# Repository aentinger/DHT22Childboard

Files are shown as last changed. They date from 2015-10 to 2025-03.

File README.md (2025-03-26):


💾 DHT22 Childboard
====================



# 📸 Image

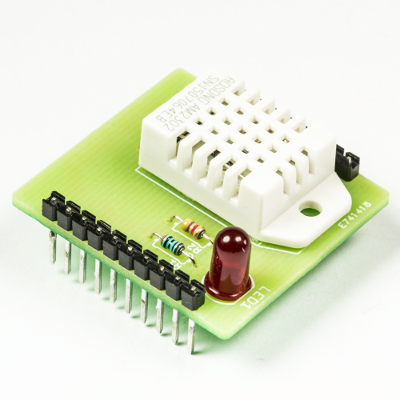
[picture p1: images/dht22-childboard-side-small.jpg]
LXRobotics P6_4 DHT22 Childboard


# 📂 Description

The LXRobotics DHT22 Humidity/Temperature Sensor Childboard is based on the known DHT22 sensor and allows the measurement of temperature and of the air humidity. For a quick and easy start, an open source Arduino library with sample programs is available.

**Features**

* Measurement of Temperature and Air Humidity
* Red Status-LED controlled by user
* Can be used with the Radioshield the Childboard Adaptershield
* Arduino Library with example programs is available on GitHub

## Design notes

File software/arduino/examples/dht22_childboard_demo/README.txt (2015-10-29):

DHT22 Arduino Library for example file dht22_childboard_demo.ino : https://github.com/markruys/arduino-DHT

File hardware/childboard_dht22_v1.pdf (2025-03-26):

Menge | Schaltplan | Bezeichnung | Farnell Bestell Nummer | Preis (1 Stück) | Gesamtpreis | Wird bestückt | Footprint | Säckchen | ESD
1 | LED1 | LED Rot, 5 mm, Uf=1.9V, If=10 mA | 1660489 | € 0,35 | € 0,35 | | | S1
1 | R1 | Widerstand, 300 R, 0.25 W | 2329916 | € 0,03 | € 0,03
1 | R2 | Widerstand, 4k7, 1/8 W | 1700245 | € 0,01 | € 0,01
1 | IC1 | DHT22 | - | € | 5,00 | € | 5,00 | Hinweis: Via Alibaba beziehen
2 | J1 | RF Childboard Connector | 1022261 | € | 0,36 | € | 0,72
| | | | Summe | | € | 6,11

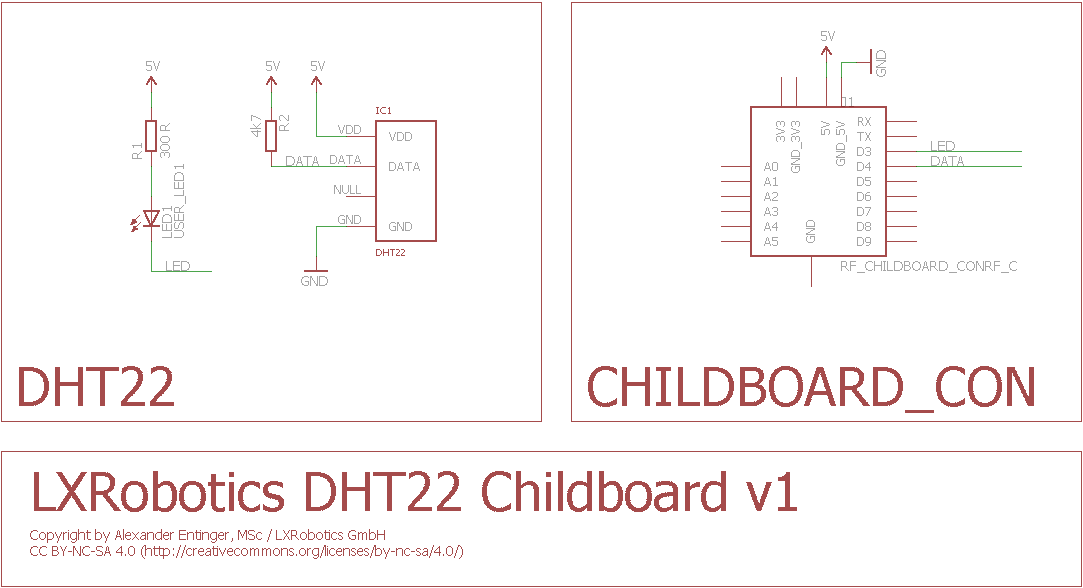
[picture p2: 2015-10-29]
hardware/lxr_childboard_dht22_v1.png

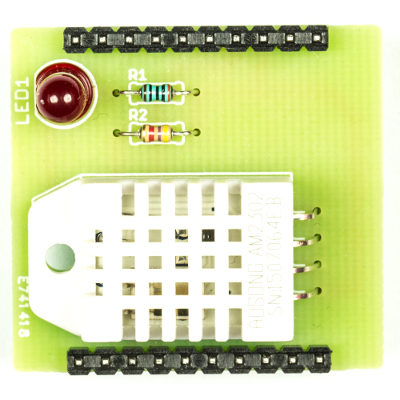
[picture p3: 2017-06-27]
images/dht22-childboard-top-small.jpg

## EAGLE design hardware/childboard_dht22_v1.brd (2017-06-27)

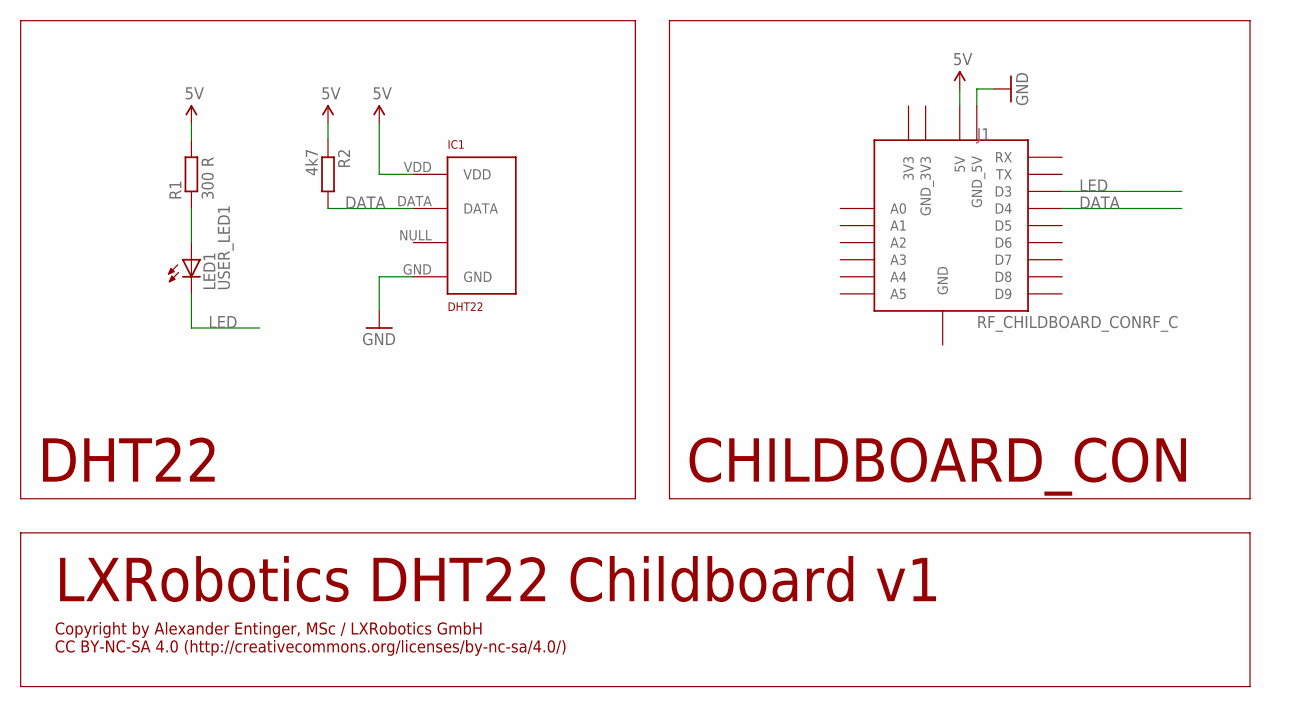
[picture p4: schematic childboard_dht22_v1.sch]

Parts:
IC1: DHT22; RHT03_DHT-22/RA
J1: RF_CHILDBOARD_CONRF_C; RF_CHILDBOARD_CON
LED1: USER_LED1; LED5MM
R1: 300 R; 0204/7
R2: 4k7; 0204/7

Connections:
5V: IC1.VDD, J1.5V, R1.2, R2.1
DATA: IC1.DATA, J1.D4, R2.2
GND: IC1.GND, J1.GND_5V
LED: J1.D3, LED1.K (C)
unnamed: LED1.A, R1.1

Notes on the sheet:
DHT22
CHILDBOARD_CON
LXRobotics DHT22 Childboard v1
Copyright by Alexander Entinger, MSc / LXRobotics GmbH CC BY-NC-SA 4.0 (http://creativecommons.org/licenses/by-nc-sa/4.0/)

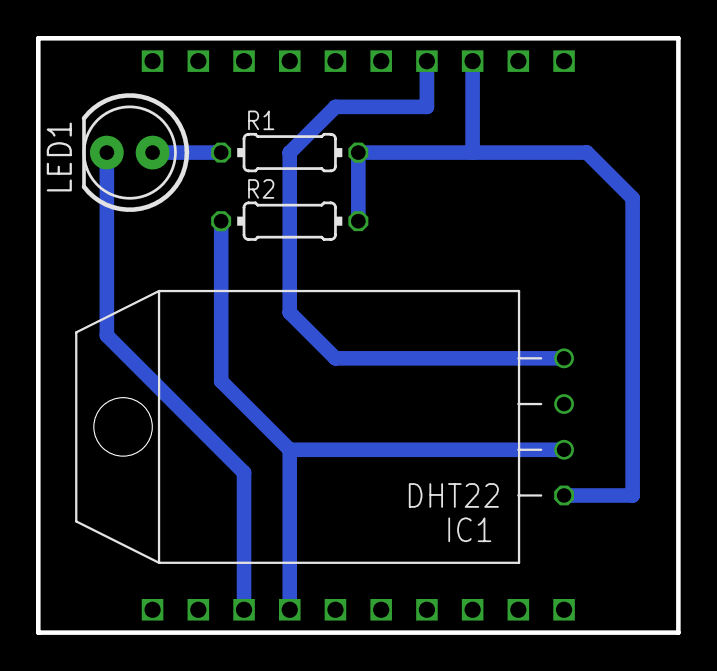
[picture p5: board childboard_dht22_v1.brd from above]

Board: 2 copper layers, 35.6 x 33.0 mm, 5 parts (0 on the bottom side), 5 nets.

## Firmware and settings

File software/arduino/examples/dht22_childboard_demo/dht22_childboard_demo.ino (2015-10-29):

/**
 * @author Alexander Entinger, MSc / LXRobotics
 * @brief this file demonstrates how to use the the LXRobotics DHT22 Childboard for reading out temperature and humidity values and displaying the via serial as well as blinking the childboard led
 * @file dht22_childboard_demo.ino
 * @license Attribution-NonCommercial-ShareAlike 4.0 Unported (CC BY-NC-SA 4.0) ( http://creativecommons.org/licenses/by-nc-sa/4.0/ )
 */

/* INCLUDES */

#include "DHT.h"

/* GLOBAL CONSTANTS */

// led pin is pin D3
static int const LED_PIN = 3;
// dht22 data pin is D4
static int const DHT22_DATA_PIN = 4;

/* GLOBAL VARIABLES */

DHT dht;

/* FUNCTIONS */

/**
 * @brief setup function is executed once
 */
void setup()
{
  // set led pin as output
  pinMode(LED_PIN, OUTPUT);
  // init DHT library
  dht.setup(DHT22_DATA_PIN);
  // init serial output
  Serial.begin(115200);
}

/**
 * @brief main loop
 */
void loop()
{
  turn_led_on();
  delay(500);
  turn_led_off();
  delay(500);

  float const humidity = dht.getHumidity();
  float const temperature = dht.getTemperature();

  Serial.print(dht.getStatusString());
  Serial.print(" | ");
  Serial.print(humidity, 1);
  Serial.print(" % | ");
  Serial.print(temperature, 1);
  Serial.println(" C ");
}

/**
 * @brief turn the led of the dht22 childboard on
 */
void turn_led_on()
{
  digitalWrite(LED_PIN, LOW);
}

/**
 * @brief turn the led of the dht22 childboard off
 */
void turn_led_off()
{
  digitalWrite(LED_PIN, HIGH);
}

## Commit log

2017-06-27 Adding hardware + images
    [childboard_dht22_v1.brd, childboard_dht22_v1.sch]
2025-03-26 Add BOM.

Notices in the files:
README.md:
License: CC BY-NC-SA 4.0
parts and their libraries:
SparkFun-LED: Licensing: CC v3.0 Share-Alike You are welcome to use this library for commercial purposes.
